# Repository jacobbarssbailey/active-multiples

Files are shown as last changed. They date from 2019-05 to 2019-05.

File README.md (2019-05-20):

# Active Multiples
This project provides tested plans for a 4HP Eurorack-format synthesizer module, containing two banks of 1 -> 3 active buffers, taking any signal at the input and precisely replicating it on the three outputs.

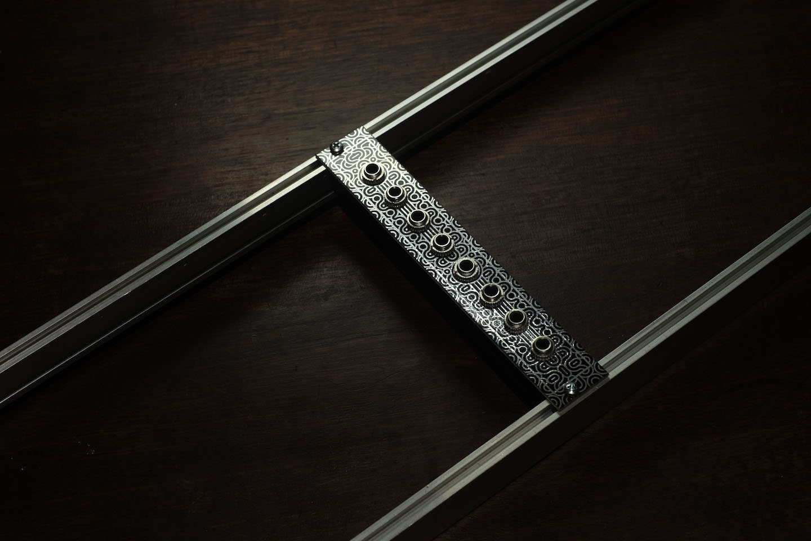
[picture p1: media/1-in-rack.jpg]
Assembled module


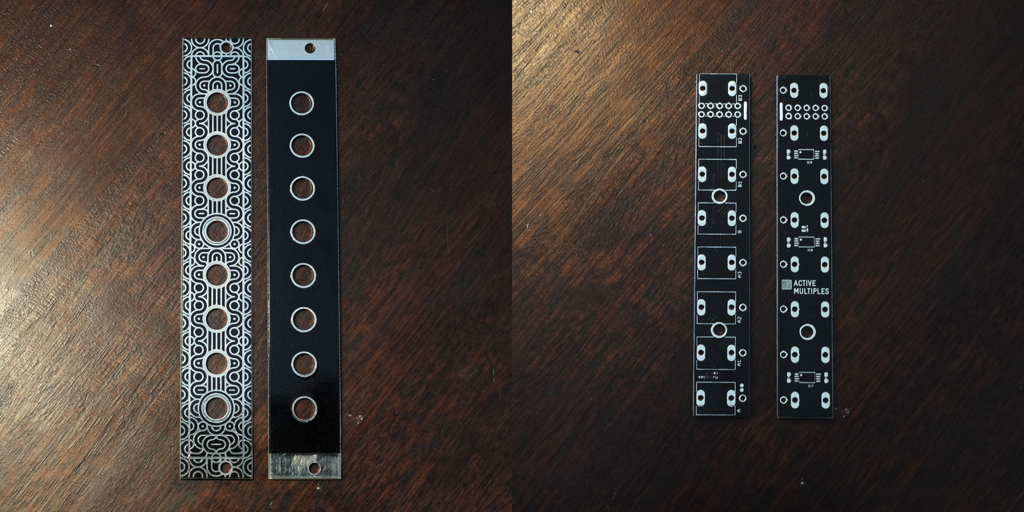
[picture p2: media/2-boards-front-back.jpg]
Boards


## BOM 

Qty | Value            | Device                  | Package             | Parts                                                |
--- | ---------------- | ----------------------- | ------------------- | ---------------------------------------------------- |
3   | TL072            | Dual op amp             | TSSOP8              | ICxx                                                 |
6   | ~100nF           | Capacitor               | 0603                | DC1 – DC6                                            |
1   |                  | 5x2                     | 2.54mm Pin          | Power                                                |
8   |                  | Inline mono jack        | Thonkconn           | A, A1, A2, A3, B, B1, B2, B3                         |

## Notes

1. Solder the power connector before soldering signal jacks. There is very little space between the jacks to reach the top of the board after they are attached.
1. Input A (labeled on PCB) drives output A1, A2, A3; Input B drives output B1, B2, B3. Input A is normalled to Input B; if this behavior isn't desired, cut jumper trace labeled A->B.

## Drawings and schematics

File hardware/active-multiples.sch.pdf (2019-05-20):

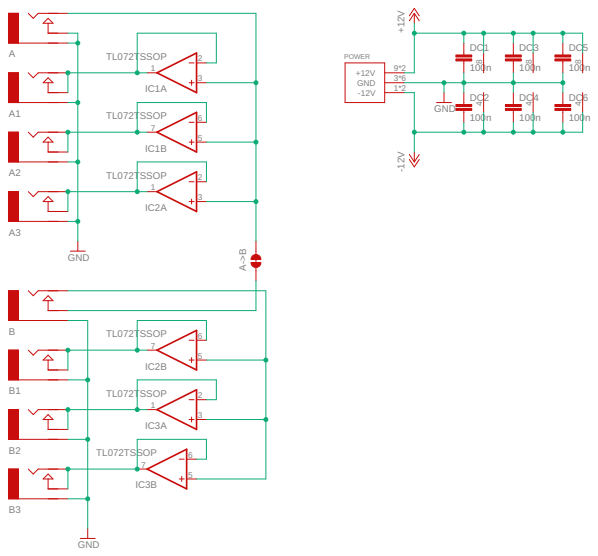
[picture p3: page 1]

-12V GND GNDGND +12V TL072TSSOP TL072TSSOP TL072TSSOP TL072TSSOP TL072TSSOP TL072TSSOP 100n 100n 100n 100n 100n 100n AA1A2A3BB1B2B3 +12V 9*2 GND 3*6 -12V 1*2 POWER 23 1IC1A 65 7IC1B 23 1IC2A 65 7IC2B 23 1IC3A 65 7IC3B 8 4 8 4 8 4 DC1 DC2 DC3 DC4 DC5 DC6 A->B

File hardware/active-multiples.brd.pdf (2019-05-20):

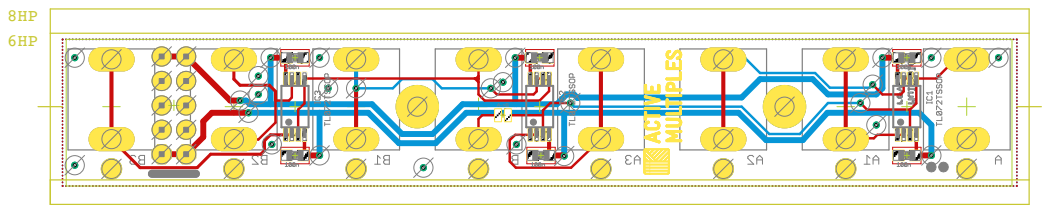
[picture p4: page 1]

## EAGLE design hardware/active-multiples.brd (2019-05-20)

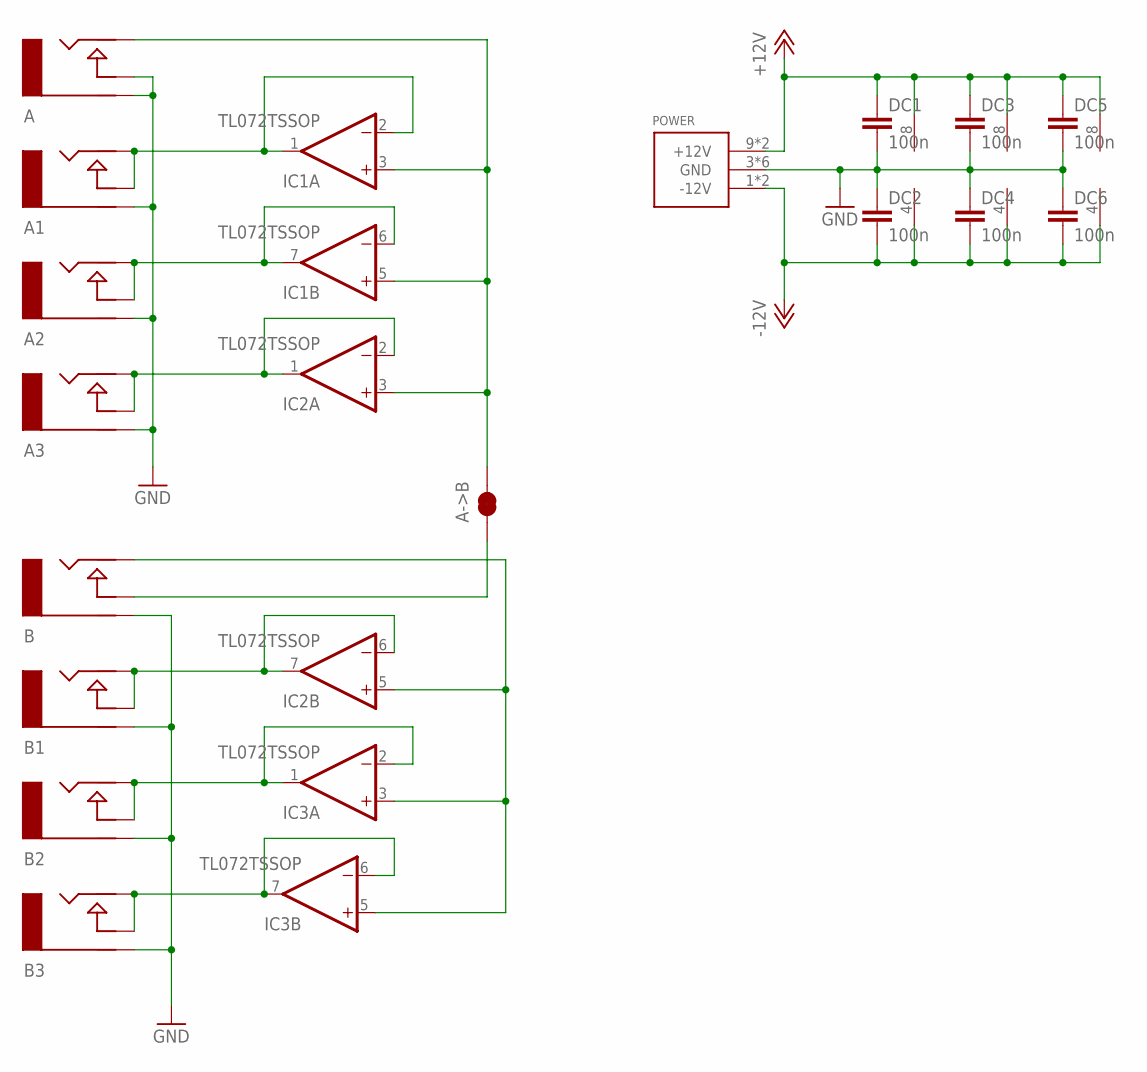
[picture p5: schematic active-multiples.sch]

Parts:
A, A1, A2, A3: AUDIO-JACKINLINE; ERTHENVAR-JACK-INLINE
A->B: JUMPER-PAD-2-NC_BY_TRACENO_SILK; PAD-JUMPER-2-NC_BY_TRACE_NO_SILK
B, B1, B2, B3: AUDIO-JACKINLINE; ERTHENVAR-JACK-INLINE
DC1, DC2, DC3, DC4, DC5, DC6: 100n; 0603-CAP
IC1, IC2, IC3: TL072TSSOP; TSSOP8
POWER: POWER_SIMPLE10; POWER_10

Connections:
+12V: DC1.1, DC3.1, DC5.1, IC1.8 (V+), IC2.8 (V+), IC3.8 (V+), POWER.9 (+12V), POWER.10 (+12V)
-12V: DC2.2, DC4.2, DC6.2, IC1.4 (V-), IC2.4 (V-), IC3.4 (V-), POWER.1 (-12V), POWER.2 (-12V)
GND: A.G (RING), A.N (NORM), A1.G (RING), A2.G (RING), A3.G (RING), B.G (RING), B1.G (RING), B2.G (RING), B3.G (RING), DC1.2, DC2.1, DC3.2, DC4.1, DC5.2, DC6.1, POWER.3 (GND), POWER.4 (GND), POWER.5 (GND), POWER.6 (GND), POWER.7 (GND), POWER.8 (GND)
unnamed: A1.N (NORM), A1.T (TIP), IC1.1 (OUT), IC1.2 (-IN)
unnamed: A->B.1, B.N (NORM)
unnamed: A3.N (NORM), A3.T (TIP), IC2.1 (OUT), IC2.2 (-IN)
unnamed: A2.N (NORM), A2.T (TIP), IC1.6 (-IN), IC1.7 (OUT)
unnamed: A.T (TIP), A->B.2, IC1.3 (+IN), IC1.5 (+IN), IC2.3 (+IN)
unnamed: B1.N (NORM), B1.T (TIP), IC2.6 (-IN), IC2.7 (OUT)
unnamed: B3.N (NORM), B3.T (TIP), IC3.6 (-IN), IC3.7 (OUT)
unnamed: B.T (TIP), IC2.5 (+IN), IC3.3 (+IN), IC3.5 (+IN)
unnamed: B2.N (NORM), B2.T (TIP), IC3.1 (OUT), IC3.2 (-IN)

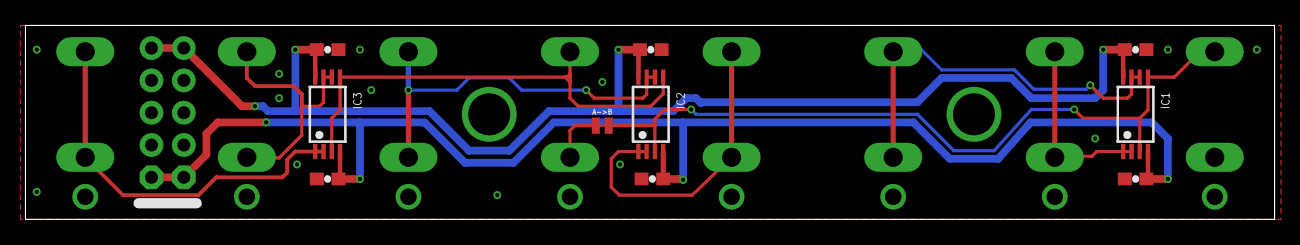
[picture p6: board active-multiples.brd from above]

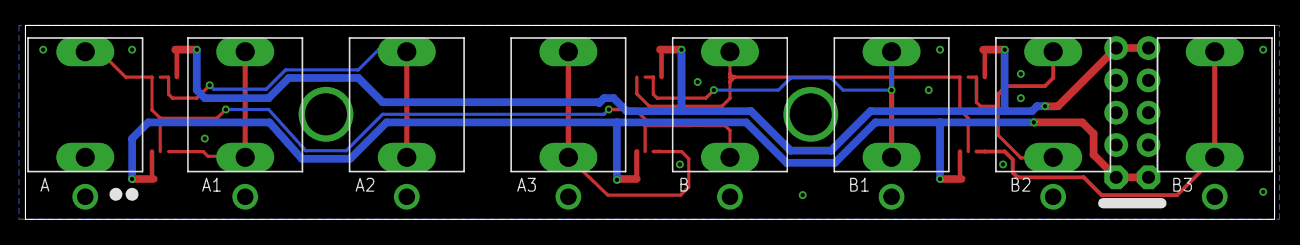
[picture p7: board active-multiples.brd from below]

Board: 2 copper layers, 98.2 x 15.2 mm, 19 parts (8 on the bottom side), 12 nets.

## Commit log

2019-05-20 bom, desc, pcbs
    [active-multiples.brd, active-multiples.sch, panel.brd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]
2019-05-20 bom formatting

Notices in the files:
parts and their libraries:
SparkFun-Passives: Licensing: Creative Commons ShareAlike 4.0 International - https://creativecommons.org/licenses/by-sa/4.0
